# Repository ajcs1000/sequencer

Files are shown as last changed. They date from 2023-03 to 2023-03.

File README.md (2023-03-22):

# 8-Step CD4017 Sequencer

***THIS HAS NOT BEEN FULLY MANUFACTURED OR TESTED. BUILD AT YOUR OWN RISK.***

This is a Eurorack 8-step sequencer made for a class, based off a modification of the Baby 8 sequencer. It uses a CD4017 decade counter, and a 555-based clock. You may want to mess around with the clock speed range if you decide to build it; it's maybe a little small and might not cover what you want it to. Same goes for LED brightness. They were a little bright when I breadboarded it, so test it out before assembling. 

This includes a faceplate design as a PCB file; as with the actual PCB it hasn't been manufactured yet and isn't guaranteed to be perfect. 

This was designed in KiCad 6, and all the needed files *should* be here - please feel free to contact me if I left something out.

Updates to come eventually, hopefully.

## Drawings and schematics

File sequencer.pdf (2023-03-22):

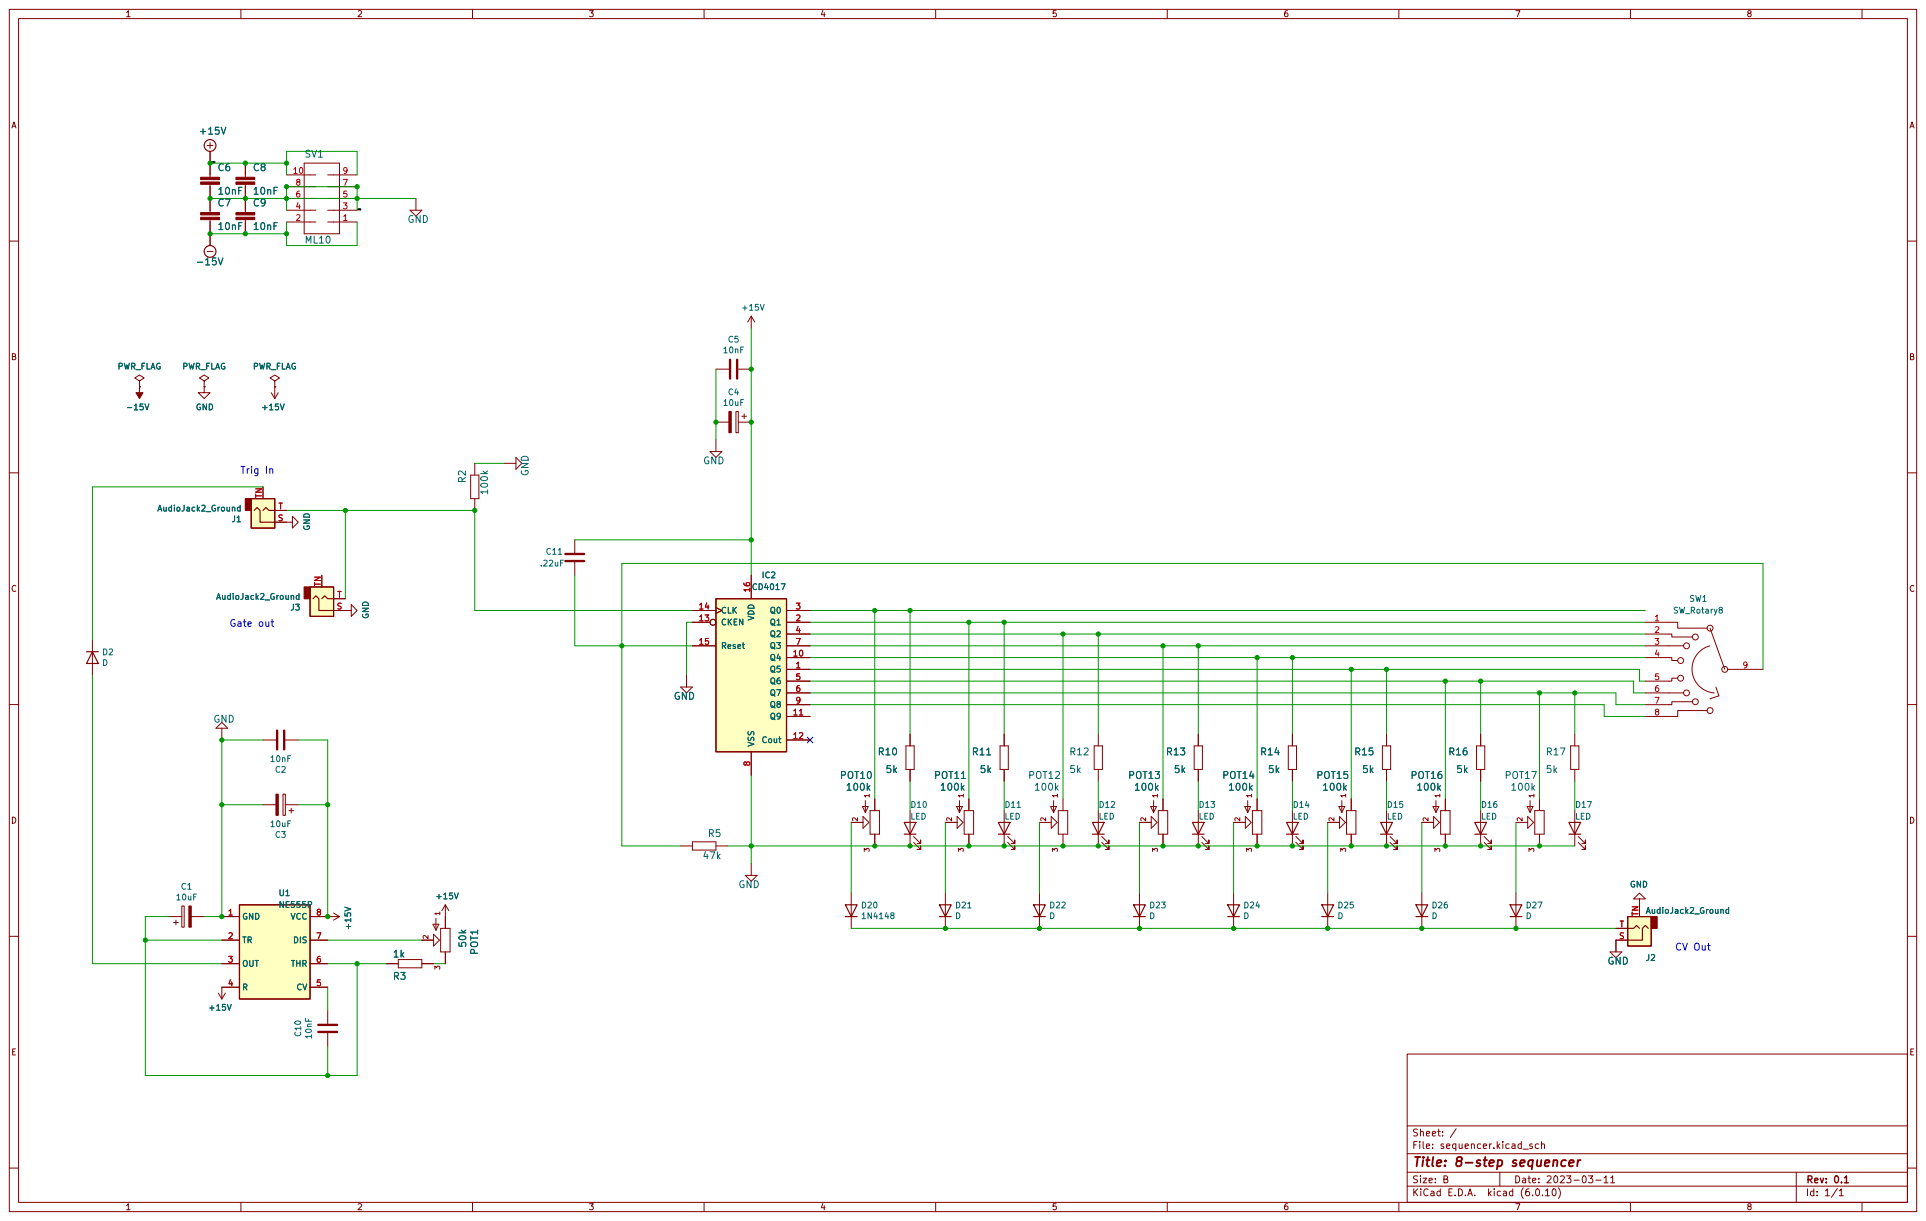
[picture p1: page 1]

Id: 1/1 Title: 8-step sequencer

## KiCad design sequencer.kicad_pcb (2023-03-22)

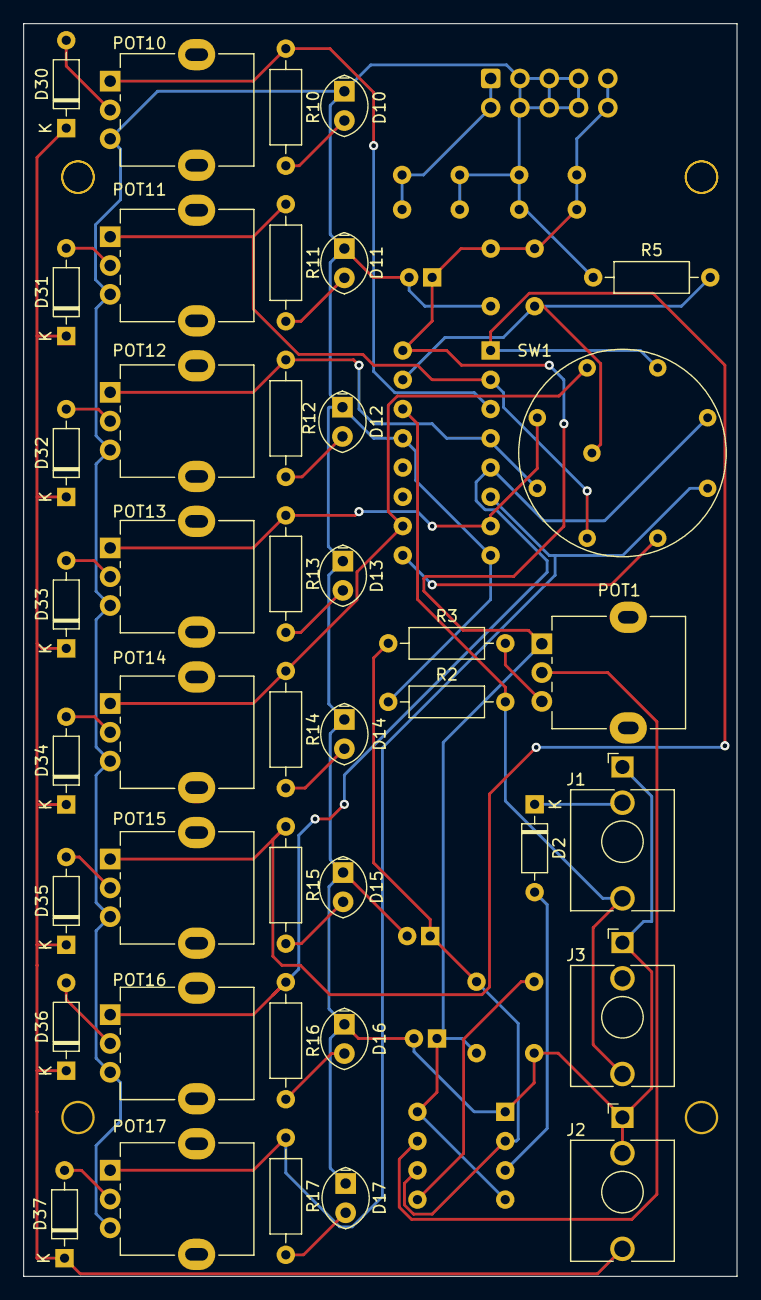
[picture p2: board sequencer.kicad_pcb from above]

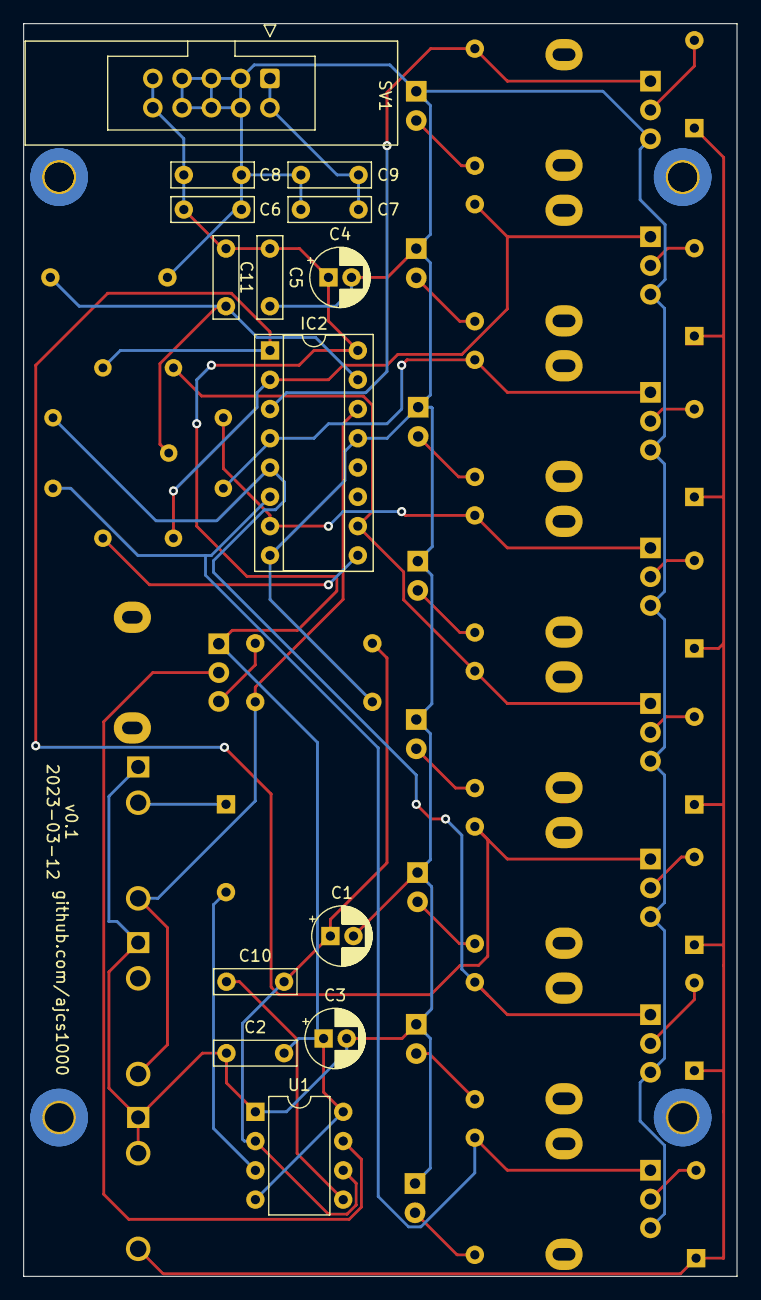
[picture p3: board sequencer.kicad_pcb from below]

Board: 2 copper layers, 61.9 x 108.7 mm, 55 parts (14 on the bottom side), 37 nets.

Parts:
C1, C3, C4: 10uF; CP_Radial_D5.0mm_P2.00mm
C2, C5, C6, C7, C8, C9, C10: 10nF; C_Rect_L7.0mm_W2.0mm_P5.00mm
C11: .22uF; C_Rect_L7.0mm_W2.0mm_P5.00mm
D2, D30, D31, D32, D33, D34, D35, D36, D37: D; D_DO-35_SOD27_P7.62mm_Horizontal
D10, D11, D12, D13, D14, D15, D16, D17: LED; LED_Oval_W5.2mm_H3.8mm
IC2: 4017; DIP-16_W7.62mm_Socket
J1, J2, J3: AudioJack2_Ground; Jack_3.5mm_QingPu_WQP-PJ398SM_Vertical_CircularHoles
POT1: 50k; Potentiometer_Alpha_RD901F-40-00D_Single_Vertical
POT10, POT11, POT12, POT13, POT14, POT15, POT16, POT17: 100k; Potentiometer_Alpha_RD901F-40-00D_Single_Vertical2mmholes
R2: 100k; R_Axial_DIN0207_L6.3mm_D2.5mm_P10.16mm_Horizontal
R3: 1k; R_Axial_DIN0207_L6.3mm_D2.5mm_P10.16mm_Horizontal
R5: 47k; R_Axial_DIN0207_L6.3mm_D2.5mm_P10.16mm_Horizontal
R10, R11, R12, R13, R14, R15, R16, R17: 5k; R_Axial_DIN0207_L6.3mm_D2.5mm_P10.16mm_Horizontal
SV1: ML10; IDC-Header_2x05_P2.54mm_Latch_Vertical
SW1: SW_Rotary8; SW_rotary8
U1: NE555P; DIP-8_W7.62mm

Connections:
+15V: C2.2, C3.1, C4.1, C5.1, C6.1, C8.1, C11.1, IC2.16 (VDD), POT1.1, SV1.9, SV1.10, U1.4 (R), U1.8 (VCC)
-15V: C7.2, C9.2, SV1.1, SV1.2
GND: C1.2, C2.1, C3.2, C4.2, C5.2, C6.2, C7.1, C8.2, C9.1, D10.1 (K), D11.1 (K), D12.1 (K), D13.1 (K), D14.1 (K), D15.1 (K), D16.1 (K), D17.1 (K), IC2.8 (VSS), IC2.13 (CKEN), J1.S, J2.S, J2.TN, J3.S, POT10.3, POT11.3, POT12.3, POT13.3, POT14.3, POT15.3, POT16.3, POT17.3, R2.1, R5.1, SV1.3, SV1.4, SV1.5, SV1.6, SV1.7, SV1.8, U1.1 (GND)
unnamed: C1.1, C10.2, R3.1, U1.2 (TR), U1.6 (THR)
unnamed: C10.1, U1.5 (CV)
unnamed: C11.2, IC2.15 (Reset), R5.2, SW1.9
unnamed: D2.1 (K), J1.TN
unnamed: D2.2 (A), U1.3 (OUT)
unnamed: D10.2 (A), R10.2
unnamed: D11.2 (A), R11.2
unnamed: D12.2 (A), R12.2
unnamed: D13.2 (A), R13.2
unnamed: D14.2 (A), R14.2
unnamed: D15.2 (A), R15.2
unnamed: D16.2 (A), R16.2
unnamed: D17.2 (A), R17.2
unnamed: D30.1 (K), D31.1 (K), D32.1 (K), D33.1 (K), D34.1 (K), D35.1 (K), D36.1 (K), D37.1 (K), J2.T
unnamed: D30.2 (A), POT10.2
unnamed: D31.2 (A), POT11.2
unnamed: D32.2 (A), POT12.2
unnamed: D33.2 (A), POT13.2
unnamed: D34.2 (A), POT14.2
unnamed: D35.2 (A), POT15.2
unnamed: D36.2 (A), POT16.2
unnamed: D37.2 (A), POT17.2
unnamed: IC2.1 (Q5), POT15.1, R15.1, SW1.5
unnamed: IC2.2 (Q1), POT11.1, R11.1, SW1.1
unnamed: IC2.3 (Q0), POT10.1, R10.1
unnamed: IC2.4 (Q2), POT12.1, R12.1, SW1.2
unnamed: IC2.5 (Q6), POT16.1, R16.1, SW1.6
unnamed: IC2.6 (Q7), POT17.1, R17.1, SW1.7
unnamed: IC2.7 (Q3), POT13.1, R13.1, SW1.3
unnamed: IC2.9 (Q8), SW1.8
unnamed: IC2.10 (Q4), POT14.1, R14.1, SW1.4
unnamed: IC2.14 (CLK), J1.T, J3.T, R2.2
unnamed: POT1.2, U1.7 (DIS)
unnamed: POT1.3, R3.2
